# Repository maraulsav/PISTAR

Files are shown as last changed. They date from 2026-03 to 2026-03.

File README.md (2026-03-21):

# PISTAR
My first custom development board. I plan to made it as a part of my drone project

## 3D View
Front



Back



## PCB
My PCB is made in KiCad These are the footprints I used
- Capacitor_SMD:C_0603_1608Metric
- Capacitor_SMD:C_0402_1005Metric
- LED_SMD:LED_WS2812B_PLCC4_5.0x5.0mm_P3.2mm
- Connector_USB:USB_C_Receptacle_HRO_TYPE-C-31-M-12
- Connector_PinHeader_2.54mm:PinHeader_1x20_P2.54mm_Vertical
- Connector_PinHeader_2.54mm:PinHeader_1x03_P2.54mm_Vertical
- Resistor_SMD:R_0402_1005Metric
- Button_Switch_SMD:SW_Push_SPST_NO_Alps_SKRK
- RP2040: Package_DFN_QFN:QFN-56-1EP_7x7mm_P0.4mm_EP3.2x3.2mm
- W25Q128JVS: Package_SON:Winbond_USON-8-1EP_3x2mm_P0.5mm_EP0.2x1.6mm
- Package_TO_SOT_SMD:SOT-23
- Crystal:Crystal_SMD_3225-4Pin_3.2x2.5mm_HandSoldering

Here is my schematic:



and my PCB:



## BOM

| Name | Purpose | Cost Per Item (USD) | Quantity | Total (USD) | Link | Distributor |
|---|---|---|---|---|---|---|
| UPS Shipping | Shipping the JLCPCB | 2.48 | 1 | 2.48 | [Link](https://cart.jlcpcb.com/shopcart/cart) | JLCPCB |
| Pin Header Delivery | Delivering the pin header | 0.83 | 1 | 0.83 | [Link](https://www.tokopedia.com/cart/checkout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) | Tokopedia |
| Pin Header 1x40 2x  | For the GPIO pins | 0.11 | 1 | 0.11 | [Link](https://www.tokopedia.com/parts-shop/pin-header-male-1-x-40-pin-254mm-single-row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) | Tokopedia |
| PCB / PCBA | PCB printing and component assembly | 78.06 | 1 | 78.06 | [Link](https://cart.jlcpcb.com/shopcart/cart) | JLCPCB |

## Additional Thingy
Thankyou for HackClub and  KiCad for making this project possible

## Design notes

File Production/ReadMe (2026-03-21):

Hi! This folder contain all the production notes that you need if you wanted to print this in JLCPCB
FIrst, there is the gerber zip files which contain all the gerber files that you need to summon the 3D looks of this dev board.
Then there is also the BOM and POS file that you need to input if you want to do a PCBA / PCB Assembly
If you don't do the PCBA you need to buy the part separated and then handsolder it

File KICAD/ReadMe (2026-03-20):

Hi! 
This folder contain all the KiCad files that I had. 
You can copy then modify some part of it, if you want

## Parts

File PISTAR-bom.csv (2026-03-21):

Name | Purpose | Cost Per Item (USD) | Quantity | Total (USD) | Link | Distributor
UPS Shipping | Shipping the JLCPCB | 2.48 | 1 | 2.48 | https://cart.jlcpcb.com/shopcart/cart | JLCPCB
Pin Header Delivery | Delivering the pin header | 0.83 | 1 | 0.83 | https://www.tokopedia.com/cart/checkout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 | Tokopedia
Pin Header 1x40 2x | For the GPIO pins | 0.11 | 1 | 0.11 | https://www.tokopedia.com/parts-shop/pin-header-male-1-x-40-pin-254mm-single-row?t_id=1774050616052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 | Tokopedia
PCB / PCBA | PCB printing and component assembly | 78.06 | 1 | 78.06 | https://cart.jlcpcb.com/shopcart/cart | JLCPCB

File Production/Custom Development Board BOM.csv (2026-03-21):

Id | Designator | Footprint | Quantity | Designation | Supplier and ref
1 | R2,R1 | R_0402_1005Metric | 2 | 5.1K
2 | R6 | R_0402_1005Metric | 1 | 10K
3 | R3,R4 | R_0402_1005Metric | 2 | 27
4 | C3,C4 | C_0402_1005Metric | 2 | 1 uF
5 | R7,R5 | R_0402_1005Metric | 2 | 1K
6 | U3 | Winbond_USON-8-1EP_3x2mm_P0.5mm_EP0.2x1.6mm | 1 | W25Q128JVS
7 | C9,C12,C2,C1,C11,C6,C5,C17,C8,C10,C7 | C_0402_1005Metric | 11 | 0.1 uF
8 | SW1 | SW_Push_SPST_NO_Alps_SKRK | 1 | SW_Push
9 | C13,C14 | C_0603_1608Metric | 2 | 10 uF
10 | J5 | PinHeader_1x03_P2.54mm_Vertical | 1 | Conn_01x03
11 | C16,C15 | C_0402_1005Metric | 2 | 15 pF
12 | D2 | LED_WS2812B_PLCC4_5.0x5.0mm_P3.2mm | 1 | WS2812B
13 | J4,J2 | PinHeader_1x20_P2.54mm_Vertical | 2 | Conn_01x20
14 | U4 | SOT-23 | 1 | MCP1700x-330xxTT
15 | J1 | USB_C_Receptacle_HRO_TYPE-C-31-M-12 | 1 | USB_C_Receptacle_USB2.0_14P
16 | U1 | QFN-56-1EP_7x7mm_P0.4mm_EP3.2x3.2mm | 1 | RP2040
17 | Y1 | Crystal_SMD_3225-4Pin_3.2x2.5mm_HandSoldering | 1 | 12 MHz

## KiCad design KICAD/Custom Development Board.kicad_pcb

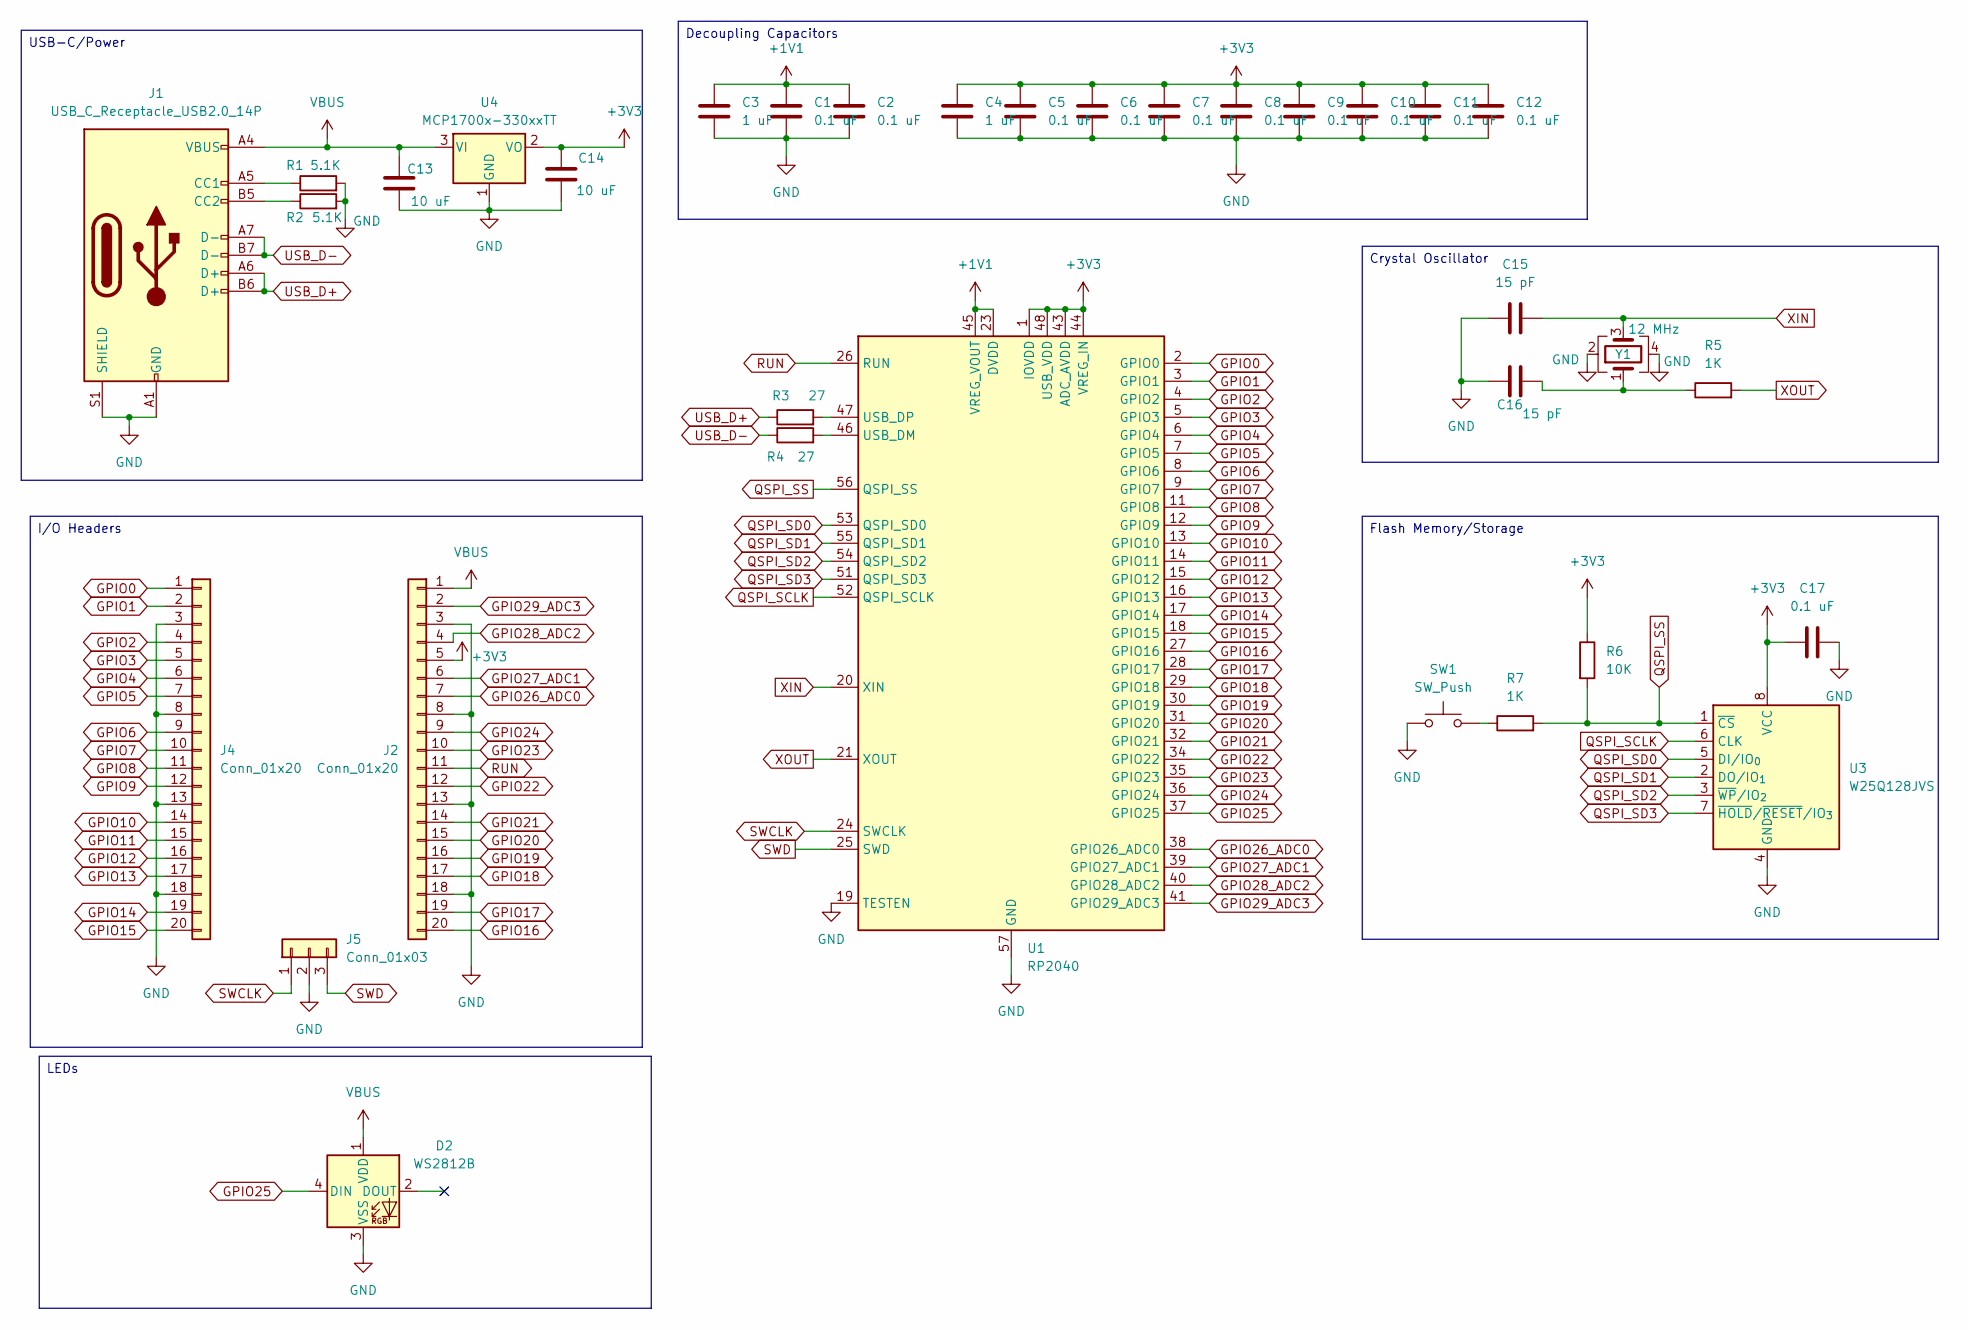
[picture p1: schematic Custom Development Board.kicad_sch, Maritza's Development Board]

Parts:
C1, C2, C5, C6, C7, C8, C9, C10, C11, C12, C17: 0.1 uF; C_0402_1005Metric
C3, C4: 1 uF; C_0402_1005Metric
C13, C14: 10 uF; C_0603_1608Metric
C15, C16: 15 pF; C_0402_1005Metric
D2: WS2812B; LED_WS2812B_PLCC4_5.0x5.0mm_P3.2mm
J1: USB_C_Receptacle_USB2.0_14P; USB_C_Receptacle_HRO_TYPE-C-31-M-12
J2, J4: Conn_01x20; PinHeader_1x20_P2.54mm_Vertical
J5: Conn_01x03; PinHeader_1x03_P2.54mm_Vertical
R1, R2: 5.1K; R_0402_1005Metric
R3, R4: 27; R_0402_1005Metric
R5, R7: 1K; R_0402_1005Metric
R6: 10K; R_0402_1005Metric
SW1: SW_Push; SW_Push_SPST_NO_Alps_SKRK
U1: RP2040; QFN-56-1EP_7x7mm_P0.4mm_EP3.2x3.2mm
U3: W25Q128JVS; Winbond_USON-8-1EP_3x2mm_P0.5mm_EP0.2x1.6mm
U4: MCP1700x-330xxTT; SOT-23
Y1: 12 MHz; Crystal_SMD_3225-4Pin_3.2x2.5mm_HandSoldering

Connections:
+1V1: C1.1, C2.1, C3.1, U1.23 (DVDD), U1.45 (VREG_VOUT), U1.50 (DVDD)
+3V3: C4.1, C5.1, C6.1, C7.1, C8.1, C9.1, C10.1, C11.1, C12.1, C14.1, C17.1, J2.5, R6.1, U1.1 (IOVDD), U1.10 (IOVDD), U1.22 (IOVDD), U1.33 (IOVDD), U1.42 (IOVDD), U1.43 (ADC_AVDD), U1.44 (VREG_IN), U1.48 (USB_VDD), U1.49 (IOVDD), U3.8 (VCC), U4.2 (VO)
GND: C1.2, C2.2, C3.2, C4.2, C5.2, C6.2, C7.2, C8.2, C9.2, C10.2, C11.2, C12.2, C13.2, C14.2, C15.1, C16.1, C17.2, D2.3 (VSS), J1.A1 (GND), J1.A12 (GND), J1.B1 (GND), J1.B12 (GND), J1.S1 (SHIELD), J2.3, J2.8, J2.13, J2.18, J4.3, J4.8, J4.13, J4.18, J5.2, R1.2, R2.2, SW1.1, U1.19 (TESTEN), U1.57 (GND), U3.4 (GND), U4.1 (GND), Y1.2, Y1.4
GPIO0: J4.1, U1.2 (GPIO0)
GPIO1: J4.2, U1.3 (GPIO1)
GPIO2: J4.4, U1.4 (GPIO2)
GPIO3: J4.5, U1.5 (GPIO3)
GPIO4: J4.6, U1.6 (GPIO4)
GPIO5: J4.7, U1.7 (GPIO5)
GPIO6: J4.9, U1.8 (GPIO6)
GPIO7: J4.10, U1.9 (GPIO7)
GPIO8: J4.11, U1.11 (GPIO8)
GPIO9: J4.12, U1.12 (GPIO9)
GPIO10: J4.14, U1.13 (GPIO10)
GPIO11: J4.15, U1.14 (GPIO11)
GPIO12: J4.16, U1.15 (GPIO12)
GPIO13: J4.17, U1.16 (GPIO13)
GPIO14: J4.19, U1.17 (GPIO14)
GPIO15: J4.20, U1.18 (GPIO15)
GPIO16: J2.20, U1.27 (GPIO16)
GPIO17: J2.19, U1.28 (GPIO17)
GPIO18: J2.17, U1.29 (GPIO18)
GPIO19: J2.16, U1.30 (GPIO19)
GPIO20: J2.15, U1.31 (GPIO20)
GPIO21: J2.14, U1.32 (GPIO21)
GPIO22: J2.12, U1.34 (GPIO22)
GPIO23: J2.10, U1.35 (GPIO23)
GPIO24: J2.9, U1.36 (GPIO24)
GPIO25: D2.4 (DIN), U1.37 (GPIO25)
GPIO26_ADC0: J2.7, U1.38 (GPIO26_ADC0)
GPIO27_ADC1: J2.6, U1.39 (GPIO27_ADC1)
GPIO28_ADC2: J2.4, U1.40 (GPIO28_ADC2)
GPIO29_ADC3: J2.2, U1.41 (GPIO29_ADC3)
unnamed: C16.2, R5.1, Y1.1
unnamed: J1.A5 (CC1), R1.1
unnamed: J1.B5 (CC2), R2.1
unnamed: R7.1, SW1.2
unnamed: R4.2, U1.46 (USB_DM)
unnamed: R3.2, U1.47 (USB_DP)
QSPI_SCLK: U1.52 (QSPI_SCLK), U3.6 (CLK)
QSPI_SD0: U1.53 (QSPI_SD0), U3.5 (DI/IO_{0})
QSPI_SD1: U1.55 (QSPI_SD1), U3.2 (DO/IO_{1})
QSPI_SD2: U1.54 (QSPI_SD2), U3.3 (~WP/IO_{2})
QSPI_SD3: U1.51 (QSPI_SD3), U3.7 (~HOLD/~RESET/IO_{3})
QSPI_SS: R6.2, R7.2, U1.56 (QSPI_SS), U3.1 (~CS)
RUN: J2.11, U1.26 (RUN)
SWCLK: J5.1, U1.24 (SWCLK)
SWD: J5.3, U1.25 (SWD)
USB_D+: J1.A6 (D+), J1.B6 (D+), R3.1
USB_D-: J1.A7 (D-), J1.B7 (D-), R4.1
VBUS: C13.1, D2.1 (VDD), J1.A4 (VBUS), J1.A9 (VBUS), J1.B4 (VBUS), J1.B9 (VBUS), J2.1, U4.3 (VI)
XIN: C15.2, U1.20 (XIN), Y1.3
XOUT: R5.2, U1.21 (XOUT)

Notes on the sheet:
Decoupling Capacitors
Flash Memory/Storage
USB-C/Power
LEDs
Crystal Oscillator
I/O Headers

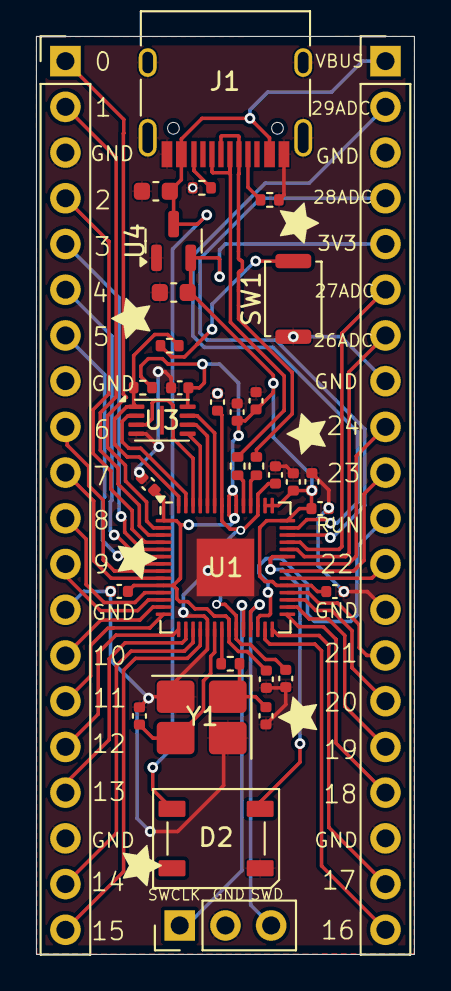
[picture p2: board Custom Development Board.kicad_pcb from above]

Board: 2 copper layers, 21.0 x 51.0 mm, 34 parts (0 on the bottom side), 53 nets.

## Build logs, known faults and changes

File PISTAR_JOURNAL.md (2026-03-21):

<!--
  This journal is auto generated by Stasis.
-->

# 3/20/2026 3 AM - Fixing All PCB Errors!

_Time spent: 1h_

YEYEYEYEYEY
I have fixed all the errors!

So, continuing from my last journal where I keep encountering the thermal relief connection to zone incomplete layers, I asked Indonesian hanckclub community regarding this issue.. So, they said that I have to adjust the values to the minimum possible number: 
like this


Yea, but the errors didn't stop to that because unfortunately there are some not connected items.. So, I have to like adjust some the component and added some vias.

After I done all of that, fixing all errors, I started to cleaning the silkscreen, deleting some unimportant notes in capacitor and resistor. Then decorating it!



This is the final PCB looks




# 3/19/2026 12 PM - Designing PCB

_Time spent: 5h_

I think it have been hours since I tried to assemble the PCB
Following the tutorial one by one.. This is my first time doing a really complex project.
But, I learnt so many things tho. Like, I just know the like moving the parts with percision features, then also the two lines with the same length, vias, and also the filling up part..

I think the hardest part assemblying this is the connecting the wires and positioning the component. The wiring itself feels like a puzzle.  Do you know the "cut the rope" game? so there is levels with like a portal, and I see that vias like that also. A really magnificent puzzle. 
I have to like retry 2 or 3 times after like assemblying it and found out some wires is not connected.

 
This is the look of my development board right now

But, I don't know why like I kept encountering this error


I have tried to follow the tutorial to solve this errors, yet, it doesn't work...
I am confused with what should I do
I have like tried to ask the #electronics channel and I have like done what they told me but it still didn't work..

Well... hum, I will update it later




# 12/28/2025 9 PM - Updating schematics

_Time spent: 1h_

Well, yeah, I search for ideas on Google. 
And there is this one video that I watched : https://www.youtube.com/watch?v=kcwvuwetgEQ
It is a really cool video talking about like how to convert RP2040 to behave like Raspberry Pi Pico, but unfortunately it is hard for me to comprehend it QvQ.. I have, like, walked through the datasheet.. yeah, in the end I decide to just add an LED to the GPIO25 to, like, detect codes that going through the custom development board. And also add 4 mounting holes just in case I wanted to, like, secure it somewhere else. 




# 12/28/2025 3 PM - Building the schematic

_Time spent: 2h_

Hi all!
I wanted to make my own development board.. 
Currently I am finished on following the schematic tutorials
The tutorials is so goodd with it I can know more about the standard of making schematics, and also ofc the component of development board and how does it affects each other. I rilly good materials there. Now I wanted to search abt things that can be added to this development board!
